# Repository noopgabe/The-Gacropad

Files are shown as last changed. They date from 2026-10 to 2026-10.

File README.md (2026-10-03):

# The GacroPad

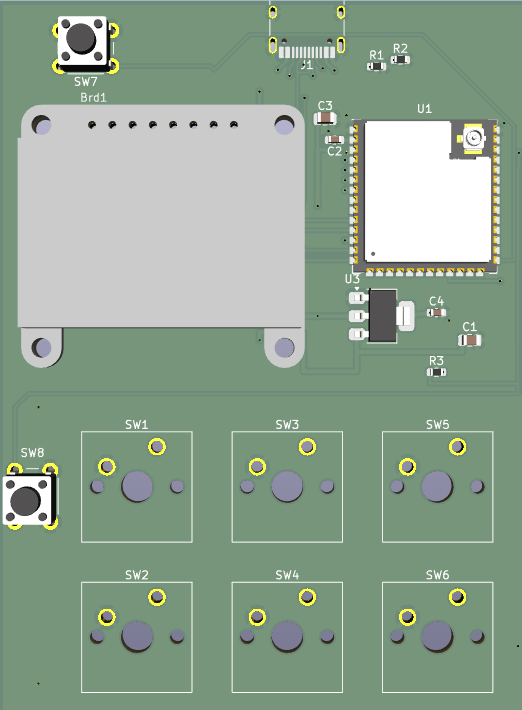
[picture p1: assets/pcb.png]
> 

A six-key macro pad that plugs into a PC as a USB keyboard, with a small OLED for whatever you feel like showing it. Time, stats, whatever. If it doesn't have it, make it.

I made this because I play Roblox. Roblox is very weird. Some games are intense, and some are calmer. If you couldn't tell, I play intensely. I also listen to music. Can you REALLY switch between music and being in the middle of a chase sequence? No. No you can't. This is why I built the GacroPad. I also need macros for some things, limited to, but not excluding:

- Complicated actions 
- Die of Death
- Soundboard

The screen helps in a way because I can see the time when I'm in a heavy chase and I can't hit F11 without getting myself hit in a chase.

---

The repo has two halves: the firmware that runs on the pad, and a GTK4 companion app. The pad is good itself. The companion app is the real business, but the firmware is where all the magic happens. The companion app is cooler, I swear on my life.

## The hardware

It's built around an **ESP32-S3-WROOM-1U**:

- a 1.3" SSD1306 128x64 I2C OLED (the address is probed at boot, so `0x3C` and `0x3D` both work)
- native USB, but \* 2: TinyUSB HID for the keyboard and media keys, and a CDC port for talking to the companion app.

Macros can send ordinary keystrokes, raw HID usages, media keys, text, and delays. They're stored in NVS, so they survive power cycles and reflashes. If that is one of your worries, let them be free!

## Building the firmware

```bash
pio run
```

That gives you `firmware.bin`, which is only the application. A _first_ flash over the ROM bootloader kinda needs the whole thing, so instead run this:

```bash
pio run -t mergedbin
```

That writes `.pio/build/gacropad/gacropad.bin`, which includes the bootloader, partition table, and app, ready to flash at offset `0x0`.

### Flashing

There's buttons. On the PCB. One is BOOT. One is RESET. Hold BOOT, and then hit RESET. After, you can flash it through various ways, but my favorite is esptool. For the sake of time, I will only place that.

```bash
esptool.py --port /dev/ttyUSB0 write_flash 0x0 .pio/build/gacropad/gacropad.bin
```

## The companion app

GTK4, via PyGObject, which means it wants the system Python:

```bash
sudo apt install python3-gi gir1.2-gtk-4.0
pip install -r companion/requirements.txt
cd companion && /usr/bin/python3 main.py
```

A plain venv usually won't have `gi`, which is why we have the `/usr/bin/python3`. The app finds the pad on its own if there's only one, and you should only have one anyway, since 2 is nuts and 3 is a mental health issue.

What it's for:

- Macro editing. Seriously, what else? Click a key to open its editor. Recording captures whatever you do but only while the editor window has focus, because why else? Just write it down on a notepad if you need to remember. This is why it works on Wayland without root. Esc stops. There's a "test fire" button, and presets if you're a baby and you don't like to record.
- OLED modes. `labels` (key names), `clock`, `stats` (CPU and memory), and `live` (two lines of text you control). The live lines are plain text pushed over serial, so anything can be there.

The key buttons push one slot at a time, meanwhile "push all" pushes all six. Of course.

## The serial protocol

Newline-delimited JSON, one request per line, one reply per line. If you're handy, this is maybe useful. _Maybe._ This usually isn't, but if you eventually figure it out, congratulations, you're a nerd.

```
{"cmd":"ping"}
{"cmd":"get","key":0}
{"cmd":"set","key":0,"slot":{"label":"K1","steps":[{"t":"raw","v":104,"hold":40}]}}
{"cmd":"press","key":0}
{"cmd":"oled","mode":"clock"}
{"cmd":"live","clock":"14:32","l1":"hello","l2":"world"}
{"cmd":"stats","cpu":12,"mem":40}
{"cmd":"reset"}
```

Replies always carry `ok`, and an `err` when it's false. The pad also emits unsolicited `{"ev":...}` lines of its own when you press a key.

Macro steps are `delay`, `text`, `media`, `raw`, `key`, `down`, and `up`, where `down` and `up` are for chords, like holding Ctrl and then tapping C.

## CAD files

Well, here's the thing. The case is not done yet. It will be done soon. Trust me, it won't be late. 

## Credits and confessions

Built with [U8g2](https://github.com/olikraus/u8g2) (thank you) and [ArduinoJson](https://github.com/bblanchon/ArduinoJson) (thank you too), and a great deal of beating the hugs out of the ESP32 Arduino HID API until it worked well.

The code comments are better than the actual code, unfortunately. I am not good at programming, or designing, or whatever. If you object, do not.

I have committed many sins (sloth, sloth, sloth, and sloth), and this is unfortunately my penance. This was lazy, but that's fine.

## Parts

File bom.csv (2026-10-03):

Item Name | Qty | Price (total) (USD) | Item link | Notes
ESP32-S3-WROOM-1U-N8 | 1 | 4.54 | https://www.lcsc.com/product-detail/C2980297.html
USB-C receptacle | 5 | 0.86 | https://www.lcsc.com/product-detail/C165948.html
10kΩ resistor | 100 | 0.39 | https://www.lcsc.com/product-detail/C965184.html
AMS1117-3.3 | 5 | 1.05 | https://www.lcsc.com/product-detail/C6186.html
Tactile button | 5 | 0.76 | https://www.lcsc.com/product-detail/C722171.html
10uF capacitor | 20 | 1.31 | https://www.lcsc.com/product-detail/C15850.html
100nF capacitor | 50 | 0.62 | https://www.lcsc.com/product-detail/C14663.html
1uF capacitor | 20 | 0.5 | https://www.lcsc.com/product-detail/C106858.html
5.1kΩ resistor | 100 | 0.15 | https://www.lcsc.com/product-detail/C23186.html
LCSC shipping + handling | N/A | 11.32 | N/A | standard shipping
JLC manufacturing + shipping | 5 | $7.38 | N/A | ditto
Adafruit oled | 1 | 19.95 | https://www.digikey.com/en/products/detail/adafruit-industries-llc/938/5774238
DigiKey shipping | N/A | 4.99 | N/A | standard usps ground advantage
Soldering iron | 1 | $10.64 | https://a.co/d/09gOBPuw | i have prime so its okie-dokie
Total Price (USD): | 64.46

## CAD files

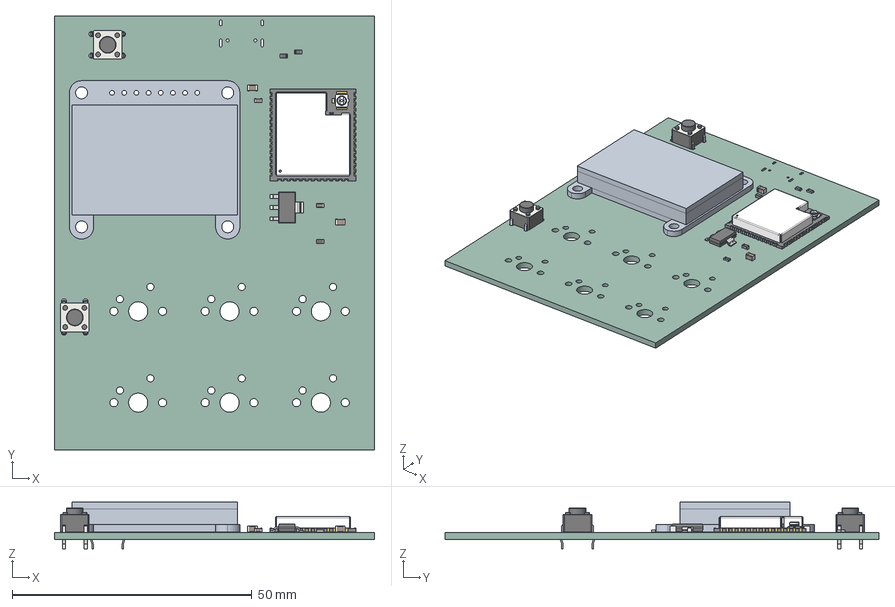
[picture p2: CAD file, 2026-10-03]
cad/gacropad.step
66.7 x 90.5 x 9.70 mm
C_0805_2012Metric x 2
R0201_20210301.STEP^R0201_20210301.STEP_Submodel-R0201_part_ DesignRootModel_ESP32-S3-WROOM-1U(2)_ESP32-S3-WROOM-1U_2 x 8
L0201_20210301.STEP^L0201_20210301.STEP_Submodel-L0201_part_ DesignRootModel_ESP32-S3-WROOM-1U(2)_ESP32-S3-WROOM-1U_2 x 2
C0201_20210301.STEP^C0201_20210301.STEP_Submodel-C0201_part_ DesignRootModel_ESP32-S3-WROOM-1U(2)_ESP32-S3-WROOM-1U_2 x 13
C0402_20210301.STEP^C0402_20210301.STEP_Submodel-C0402_part_ DesignRootModel_ESP32-S3-WROOM-1U(2)_ESP32-S3-WROOM-1U_2
I-IPEX.STEP^I-IPEX.STEP_Submodel-IPEX_3P_part_DesignRootModel_ ESP32-S3-WROOM-1U(2)_ESP32-S3-WROOM-1U_2
DFN1006.STEP^DFN1006.STEP_Submodel-SOD882_part_DesignRootModel_ ESP32-S3-WROOM-1U(2)_ESP32-S3-WROOM-1U_2
SOP8_rev1_20210308.STEP^SOP8_rev1_20210308.STEP_Submodel-SOP8_1P27_6P6_ part_DesignRootModel_ESP32-S3-WROOM-1U(2)_ESP32-S3-WROOM-1U_2
ESP32-S3_20210301.STEP^ESP32-S3_20210301.STEP_Submodel-QFN56_0P4_7_ part_DesignRootModel_ESP32-S3-WROOM-1U(2)_ESP32-S3-WROOM-1U_2
XTAL3225_20210301.STEP^XTAL3225_20210301.STEP_Submodel-XTAL3225_part_ DesignRootModel_ESP32-S3-WROOM-1U(2)_ESP32-S3-WROOM-1U_2
uid__4-111^DesignRootModel_ESP32-S3-WROOM-1U(2)_ESP32-S3-WROOM-1U_2
uid__4-112^DesignRootModel_ESP32-S3-WROOM-1U(2)_ESP32-S3-WROOM-1U_2
uid__4-113^DesignRootModel_ESP32-S3-WROOM-1U(2)_ESP32-S3-WROOM-1U_2
uid__4-130^DesignRootModel_ESP32-S3-WROOM-1U(2)_ESP32-S3-WROOM-1U_2
uid__4-131^DesignRootModel_ESP32-S3-WROOM-1U(2)_ESP32-S3-WROOM-1U_2
uid__4-132^DesignRootModel_ESP32-S3-WROOM-1U(2)_ESP32-S3-WROOM-1U_2
uid__4-148^DesignRootModel_ESP32-S3-WROOM-1U(2)_ESP32-S3-WROOM-1U_2
uid__4-149^DesignRootModel_ESP32-S3-WROOM-1U(2)_ESP32-S3-WROOM-1U_2
uid__4-150^DesignRootModel_ESP32-S3-WROOM-1U(2)_ESP32-S3-WROOM-1U_2
uid__1-253^DesignRootModel_ESP32-S3-WROOM-1U(2)_ESP32-S3-WROOM-1U_2
uid__1-254^DesignRootModel_ESP32-S3-WROOM-1U(2)_ESP32-S3-WROOM-1U_2
uid__1-256^DesignRootModel_ESP32-S3-WROOM-1U(2)_ESP32-S3-WROOM-1U_2
uid__1-257^DesignRootModel_ESP32-S3-WROOM-1U(2)_ESP32-S3-WROOM-1U_2
uid__1-266^DesignRootModel_ESP32-S3-WROOM-1U(2)_ESP32-S3-WROOM-1U_2
uid__1-269^DesignRootModel_ESP32-S3-WROOM-1U(2)_ESP32-S3-WROOM-1U_2
uid__1-270^DesignRootModel_ESP32-S3-WROOM-1U(2)_ESP32-S3-WROOM-1U_2
uid__1-271^DesignRootModel_ESP32-S3-WROOM-1U(2)_ESP32-S3-WROOM-1U_2
uid__1-272^DesignRootModel_ESP32-S3-WROOM-1U(2)_ESP32-S3-WROOM-1U_2
uid__1-273^DesignRootModel_ESP32-S3-WROOM-1U(2)_ESP32-S3-WROOM-1U_2
uid__1-274^DesignRootModel_ESP32-S3-WROOM-1U(2)_ESP32-S3-WROOM-1U_2
uid__1-275^DesignRootModel_ESP32-S3-WROOM-1U(2)_ESP32-S3-WROOM-1U_2
uid__1-276^DesignRootModel_ESP32-S3-WROOM-1U(2)_ESP32-S3-WROOM-1U_2
uid__1-277^DesignRootModel_ESP32-S3-WROOM-1U(2)_ESP32-S3-WROOM-1U_2
uid__1-280^DesignRootModel_ESP32-S3-WROOM-1U(2)_ESP32-S3-WROOM-1U_2
uid__1-292^DesignRootModel_ESP32-S3-WROOM-1U(2)_ESP32-S3-WROOM-1U_2
uid__1-293^DesignRootModel_ESP32-S3-WROOM-1U(2)_ESP32-S3-WROOM-1U_2
uid__1-297^DesignRootModel_ESP32-S3-WROOM-1U(2)_ESP32-S3-WROOM-1U_2
uid__1-300^DesignRootModel_ESP32-S3-WROOM-1U(2)_ESP32-S3-WROOM-1U_2
uid__1-301^DesignRootModel_ESP32-S3-WROOM-1U(2)_ESP32-S3-WROOM-1U_2
uid__1-302^DesignRootModel_ESP32-S3-WROOM-1U(2)_ESP32-S3-WROOM-1U_2
uid__1-303^DesignRootModel_ESP32-S3-WROOM-1U(2)_ESP32-S3-WROOM-1U_2
uid__1-307^DesignRootModel_ESP32-S3-WROOM-1U(2)_ESP32-S3-WROOM-1U_2
uid__1-313^DesignRootModel_ESP32-S3-WROOM-1U(2)_ESP32-S3-WROOM-1U_2
uid__1-319^DesignRootModel_ESP32-S3-WROOM-1U(2)_ESP32-S3-WROOM-1U_2
uid__1-320^DesignRootModel_ESP32-S3-WROOM-1U(2)_ESP32-S3-WROOM-1U_2
uid__1-321^DesignRootModel_ESP32-S3-WROOM-1U(2)_ESP32-S3-WROOM-1U_2
uid__1-328^DesignRootModel_ESP32-S3-WROOM-1U(2)_ESP32-S3-WROOM-1U_2
uid__1-332^DesignRootModel_ESP32-S3-WROOM-1U(2)_ESP32-S3-WROOM-1U_2
uid__1-333^DesignRootModel_ESP32-S3-WROOM-1U(2)_ESP32-S3-WROOM-1U_2
uid__1-334^DesignRootModel_ESP32-S3-WROOM-1U(2)_ESP32-S3-WROOM-1U_2
uid__1-335^DesignRootModel_ESP32-S3-WROOM-1U(2)_ESP32-S3-WROOM-1U_2
uid__1-336^DesignRootModel_ESP32-S3-WROOM-1U(2)_ESP32-S3-WROOM-1U_2
uid__1-337^DesignRootModel_ESP32-S3-WROOM-1U(2)_ESP32-S3-WROOM-1U_2
uid__1-338^DesignRootModel_ESP32-S3-WROOM-1U(2)_ESP32-S3-WROOM-1U_2
uid__1-339^DesignRootModel_ESP32-S3-WROOM-1U(2)_ESP32-S3-WROOM-1U_2
uid__1-340^DesignRootModel_ESP32-S3-WROOM-1U(2)_ESP32-S3-WROOM-1U_2
uid__1-341^DesignRootModel_ESP32-S3-WROOM-1U(2)_ESP32-S3-WROOM-1U_2
uid__1-342^DesignRootModel_ESP32-S3-WROOM-1U(2)_ESP32-S3-WROOM-1U_2
uid__1-343^DesignRootModel_ESP32-S3-WROOM-1U(2)_ESP32-S3-WROOM-1U_2
uid__1-344^DesignRootModel_ESP32-S3-WROOM-1U(2)_ESP32-S3-WROOM-1U_2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

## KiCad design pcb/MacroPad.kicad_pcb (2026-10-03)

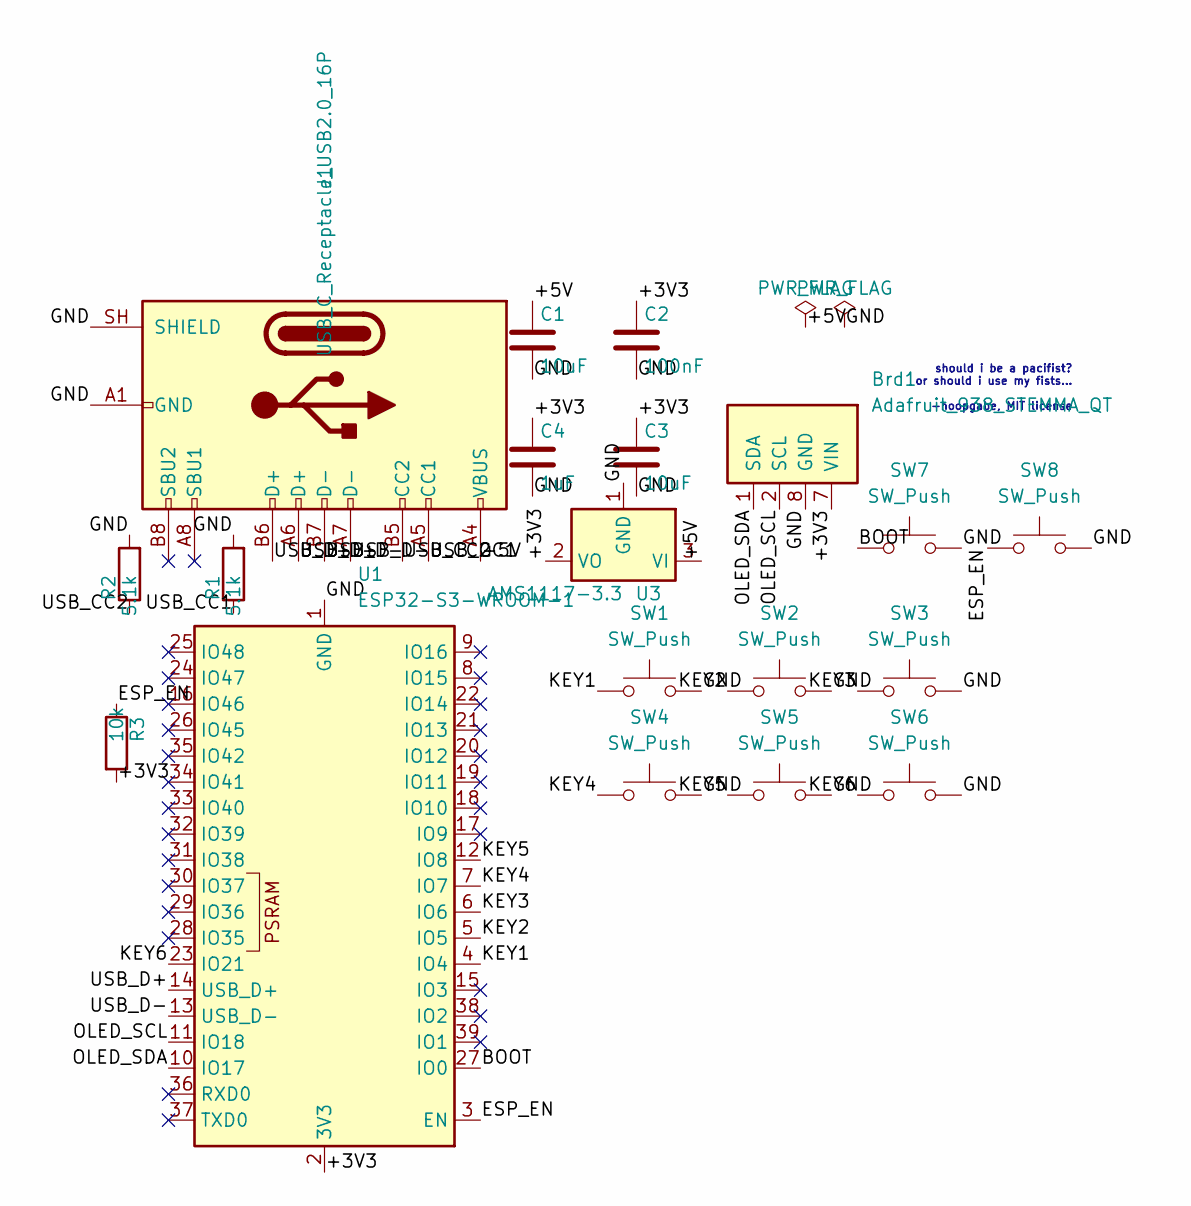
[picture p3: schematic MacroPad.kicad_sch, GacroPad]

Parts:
Brd1: Adafruit_938_STEMMA_QT
C1, C3: 10uF; C_0805_2012Metric
C2: 100nF; C_0603_1608Metric
C4: 1uF; C_0603_1608Metric
J1: USB_C_Receptacle_USB2.0_16P; USB_C_Receptacle_HRO_TYPE-C-31-M-12
R1, R2: 5.1k; R_0603_1608Metric
R3: 10k; R_0603_1608Metric
SW1, SW2, SW3, SW4, SW5, SW6: SW_Push; SW_Cherry_MX_1.00u_PCB
SW7, SW8: SW_Push; SW_PUSH_6mm_H5mm
U1: ESP32-S3-WROOM-1; ESP32-S3-WROOM-1U
U3: AMS1117-3.3; SOT-223-3_TabPin2; MPN AMS1117-3.3

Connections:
/+3V3: Brd1.7 (VIN), C2.1, C3.1, C4.1, R3.2, U1.2 (3V3), U3.2 (VO)
/+5V: C1.1, J1.A4 (VBUS), J1.A9 (VBUS), J1.B4 (VBUS), J1.B9 (VBUS), U3.3 (VI)
/BOOT: SW7.1, U1.27 (IO0)
/ESP_EN: R3.1, SW8.1, U1.3 (EN)
/GND: Brd1.8 (GND), C1.2, C2.2, C3.2, C4.2, J1.A1 (GND), J1.A12 (GND), J1.B1 (GND), J1.B12 (GND), J1.SH (SHIELD), R1.2, R2.2, SW1.2, SW2.2, SW3.2, SW4.2, SW5.2, SW6.2, SW7.2, SW8.2, U1.1 (GND), U1.40 (GND), U1.41 (GND), U3.1 (GND)
/KEY1: SW1.1, U1.4 (IO4)
/KEY2: SW2.1, U1.5 (IO5)
/KEY3: SW3.1, U1.6 (IO6)
/KEY4: SW4.1, U1.7 (IO7)
/KEY5: SW5.1, U1.12 (IO8)
/KEY6: SW6.1, U1.23 (IO21)
/OLED_SCL: Brd1.2 (SCL), U1.11 (IO18)
/OLED_SDA: Brd1.1 (SDA), U1.10 (IO17)
/USB_CC1: J1.A5 (CC1), R1.1
/USB_CC2: J1.B5 (CC2), R2.1
/USB_D+: J1.A6 (D+), J1.B6 (D+), U1.14 (USB_D+)
/USB_D-: J1.A7 (D-), J1.B7 (D-), U1.13 (USB_D-)

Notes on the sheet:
should i be a pacifist? or should i use my fists... -noopgabe, MIT license

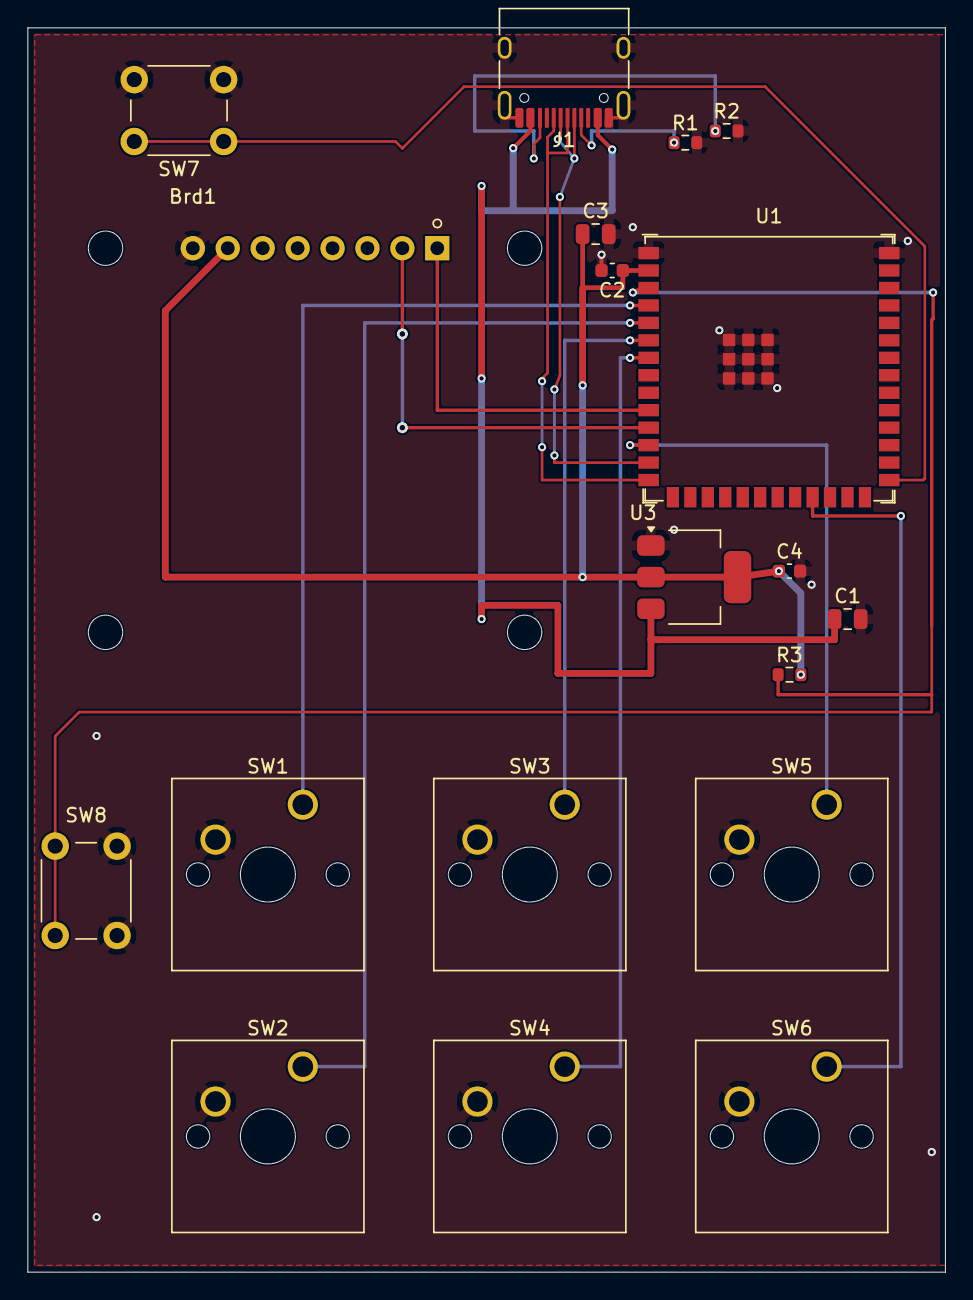
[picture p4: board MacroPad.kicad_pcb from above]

Board: 2 copper layers, 66.7 x 90.5 mm, 19 parts (0 on the bottom side), 17 nets.

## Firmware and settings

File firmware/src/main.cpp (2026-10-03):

// GacroPad firmware v1 with ESP32-S3-WROOM-1U, Arduino + Tiny USB. 
// I have nothing funny to say anymore

// Companion app talks newline-JSON over serial and mooches this thing on the cheek whenever it needs to change stuff.  
// The OLED is a 1.3" SH1106 128x64 I2C display.

#include <Arduino.h>
#include <Preferences.h>
#include <Wire.h>
#include <U8g2lib.h>
#include <ArduinoJson.h>
#include "USB.h"
#include "USBHIDKeyboard.h"
#include "USBHIDConsumerControl.h"

#define FW_VERSION "1.0.0"
#define NKEYS 6
#define PIN_OLED_SDA 46
#define PIN_OLED_SCL 45

static const uint8_t KEY_PINS[NKEYS] = {10, 9, 8, 7, 6, 40};
static const uint8_t DEFAULT_RAW[NKEYS] = {0x68, 0x69, 0x6A, 0x6B, 0x6C, 0x6D}; // F13-F18
static const char *SLOT_KEYS[NKEYS] = {"m0", "m1", "m2", "m3", "m4", "m5"};
#define MAX_STEPS 64
#define MAX_JSON 3072
#define DEBOUNCE_MS 25
#define LABEL_MAX 10

USBHIDKeyboard Keyboard;
USBHIDConsumerControl Consumer;
Preferences prefs;
U8G2_SH1106_128X64_NONAME_F_HW_I2C u8g2(U8G2_R0, U8X8_PIN_NONE, PIN_OLED_SCL, PIN_OLED_SDA);

struct Live {
    String clock = "--:--"; 
    String date = "";
    String l1 = "GacroPad";
    String l2 = "";
    int cpu = -1, mem = -1;
} live;
String oledMode = "labels";
int lastKey = -1;
uint32_t lastKeyAt = 0;
bool playing = false;

static bool keyValid(int k) { return k >= 0 && k < NKEYS; }

static String defaultSlot(int k) {
    char b[128];
    snprintf(b, sizeof b,
             "{\"label\":\"K%d\",\"steps\":[{\"t\":\"raw\",\"v\":%d,\"hold\":40}]}",
             k + 1, DEFAULT_RAW[k]);
    return String(b);
}

// flowers bloom in your heart
static String slotLabel(const char *json) {
    JsonDocument d;
    if (deserializeJson(d, json)) return "?";
    const char *l = d["label"] | "?";
    return String(l).substring(0, LABEL_MAX);
}

// Labels are cached: reading them from NVS every OLED frame is 6 flash lookups per 200ms.
static String slotLabels[NKEYS];

// getString's String overload has no length cap; the char* one silently drops slots too big to read.
static String loadSlot(int k) {
    String s = prefs.getString(SLOT_KEYS[k], "");
    if (!s.length()) { s = defaultSlot(k); prefs.putString(SLOT_KEYS[k], s); }
    return s;
}

// The one place a slot changes: NVS and the label cache move together, or they drift.
static void setSlot(int k, const char *json) {
    prefs.putString(SLOT_KEYS[k], json);
    slotLabels[k] = slotLabel(json);
}

static void loadLabels() {
    for (int k = 0; k < NKEYS; k++) {
        String s = loadSlot(k);
        slotLabels[k] = slotLabel(s.c_str());
    }
}

// Macro playback. The core functionality, how nice. 
static void playSteps(JsonArray steps) {
    int n = 0; 
    for (JsonObject st : steps) {
        if (++n > MAX_STEPS) break;
        const char *t = st["t"] | "";
        if (!strcmp(t, "delay")) {
            delay(st["ms"] | 50);
        } else if (!strcmp(t, "text")) {
            const char *s = st["s"] | "";
            Keyboard.print(s);
            delay(15);
        } else if (!strcmp(t, "media")) {
            uint16_t v = st["v"] | 0;
            if (v) { Consumer.press(v); delay(st["hold"] | 120); Consumer.release(); }
            delay(15);
        } else if (!strcmp(t, "raw")) {
            uint8_t v = st["v"] | 0;
            if (v) { Keyboard.pressRaw(v); delay(st["hold"] | 40); Keyboard.releaseRaw(v); }
            delay(15);
        } else if (!strcmp(t, "key")) {
            uint8_t v = st["v"] | 0;
            if (v) { Keyboard.press(v); delay(st["hold"] | 40); Keyboard.release(v); }
            delay(15);
        } else if (!strcmp(t, "down")) {
            uint8_t v = st["v"] | 0;
            if (v) Keyboard.press(v); 
        } else if (!strcmp(t, "up")) {
            uint8_t v = st["v"] | 0;
            if (v) Keyboard.release(v); // release(), not releaseRaw(): an "up" step pairs with a press()
            delay(10);
      }
    }
    Keyboard.releaseAll();
    Consumer.release();
}

static void playKey(int k) {
    if (!keyValid(k) || playing) return;
    playing = true;
    lastKey = k;
    lastKeyAt = millis();
    Serial.printf("{\"ev\":\"play\",\"key\":%d}\n", k);
    String slot = loadSlot(k);
    JsonDocument d;
    if (!deserializeJson(d, slot) && d["steps"].is<JsonArray>())
        playSteps(d["steps"].as<JsonArray>());
    playing = false;
}

// Serial stuff
static char lineBuf[MAX_JSON + 64];
static size_t lineLen = 0;

static void reply(JsonDocument &d) {
    serializeJson(d, Serial);
    Serial.println();
}

static void handleLine(const char *line) {
    JsonDocument d;
    JsonDocument out;
    if (deserializeJson(d, line)) { out["ok"] = false; out["err"] = "json"; reply(out); return; }
    const char *cmd = d["cmd"] | "";
    if (!strcmp(cmd, "ping")) {
        out ["ok"] = true; out ["proto"] = 1; out["fw"] = FW_VERSION; out["keys"] = NKEYS;
    } else if (!strcmp(cmd, "get")) {
        int k = d["key"] | -1;
        if (!keyValid(k)) { out["ok"] = false; out["err"] = "key"; }
        else {
            JsonDocument s;
            deserializeJson(s, loadSlot(k));
            out["ok"] = true; out["slot"] = s.as<JsonObjectConst>();
        }
    } else if (!strcmp(cmd, "set")) {
        int k = d["key"] | -1;
        if (!keyValid(k) || !d["slot"].is<JsonObject>()) { out["ok"] = false; out["err"] = "arg"; }
        else {
            String s;
            serializeJson(d["slot"], s);
            if (s.length() > MAX_JSON) { out["ok"] = false; out["err"] = "too big"; }
            else { setSlot(k, s.c_str()); out["ok"] = true; }
        }
    } else if (!strcmp(cmd, "press")) {
        int k = d["key"] | -1;
        if (!keyValid(k)) { out["ok"] = false; out["err"] = "key"; }
        else { out["ok"] = true; reply(out); playKey(k); return; }
    } else if (!strcmp(cmd, "oled")) {
        const char *m = d["mode"] | "";
        if (strcmp(m, "labels") && strcmp(m, "clock") && strcmp(m, "stats") && strcmp(m, "live")) {
            out["ok"] = false; out["err"] = "mode";
        } else { oledMode = m; prefs.putString("oledmode", m); out["ok"] = true; }
    } else if (!strcmp(cmd, "live")) {
        // Clipped to what the 6x10 font fits, here once, instead of per frame in every draw function.
        if (d["clock"].is<const char *>()) live.clock = String((const char *)d["clock"]).substring(0, 21);
        if (d["date"].is<const char *>()) live.date = String((const char *)d["date"]).substring(0, 20);
        if (d["l1"].is<const char *>()) live.l1 = String((const char *)d["l1"]).substring(0, 21);
        if (d["l2"].is<const char *>()) live.l2 = String((const char *)d["l2"]).substring(0, 21);
        out["ok"] = true;
    } else if (!strcmp(cmd, "stats")) {
        // Only the stats screen reads cpu/mem; writing them into live.l2 would clobber live mode's line 2.
        if (d["cpu"].is<int>()) live.cpu = d["cpu"];
        if (d["mem"].is<int>()) live.mem = d["mem"];
        out["ok"] = true;
    } else if (!strcmp(cmd, "reset")) {
        for (int k = 0; k < NKEYS; k++) { String s = defaultSlot(k); setSlot(k, s.c_str()); }
        oledMode = "labels";
        prefs.putString("oledmode", oledMode);
        out["ok"] = true;
    } else {
        out["ok"] = false; out["err"] = "cmd";
    }
    reply(out);
}

static void pollSerial() {
    while (Serial.available()) {
        char c = (char)Serial.read();
        if (c == '\n') {
            lineBuf[lineLen] = 0;
            if (lineLen) handleLine(lineBuf);
            lineLen = 0;
        } else if (c != '\r' && lineLen < sizeof(lineBuf) - 1) {
            lineBuf[lineLen++] = c;
        }
    }
}

// The buttons! 
static uint8_t stableState[NKEYS] = {HIGH, HIGH, HIGH, HIGH, HIGH, HIGH}; 
static uint8_t candState[NKEYS] = {HIGH, HIGH, HIGH, HIGH, HIGH, HIGH};
static uint32_t candSince[NKEYS] = {0};

static void pollKeys() {
    uint32_t now = millis();
    for (int k = 0; k < NKEYS; k++) {
        uint8_t r = digitalRead(KEY_PINS[k]);
        if (r == stableState[k]) { candState[k] = r; continue; }                        // bounced back, drop the candidate
        if (r != candState[k]) { candState[k] = r; candSince[k] = now; continue; }      // new candidate, restart the timer
        if (now - candSince[k] < DEBOUNCE_MS) continue;                                // candidate hasn't settled yet
        stableState[k] = r;
        if (r == LOW) {
            Serial.printf("{\"ev\":\"press\",\"key\":%d}\n", k);
            playKey(k);
        }
    }
}

// The OLED! 
static void drawLabels() {
    u8g2.setFont(u8g2_font_6x10_tf);
    u8g2.drawStr(0, 9, "GacroPad");
    u8g2.drawStr(128 - 6 * (int)live.clock.length(), 9, live.clock.c_str());
    for (int k = 0; k < NKEYS; k++) {
        int col = k % 2, row = k /2;
        int x = col * 64, y = 12 + row * 14;
        char l[LABEL_MAX + 4]; // key digits, ':', label, terminator
        snprintf(l, sizeof l, "%d:%s", k + 1, slotLabels[k].c_str());
        if (k == lastKey && millis() - lastKeyAt < 800) {
            u8g2.drawBox(x, y - 10, 63, 12);
            u8g2.setDrawColor(0);
            u8g2.drawStr(x + 2, y - 1, l);
            u8g2.setDrawColor(1);
        } else {
            u8g2.drawStr(x + 2, y - 1, l);
        }
    }
    u8g2.drawStr(0, 63, live.l2.c_str());
}

static void drawClock() {
    u8g2.setFont(u8g2_font_logisoso16_tr);
    u8g2.drawStr(22, 32, live.clock.c_str());
    u8g2.setFont(u8g2_font_6x10_tf);
    u8g2.drawStr(24, 46, live.date.c_str());
    u8g2.drawStr(0, 63, live.l1.c_str());
}

static void drawStats() {
    char b[32];
    u8g2.setFont(u8g2_font_6x10_tr);
    u8g2.drawStr(0, 12, "GacroPad stats");
    if (live.cpu < 0) strcpy(b, "CPU: idk (no sync)");
    else snprintf(b, sizeof b, "CPU: %d%% MEM: %d%%", live.cpu, live.mem);
    u8g2.drawStr(0, 28, b);
    snprintf(b, sizeof b, "up %lus", (unsigned long)(millis() / 1000));
    u8g2.drawStr(0, 42, b);
    u8g2.drawStr(0, 63, live.clock.c_str());
}

static void drawLive() {
    u8g2.setFont(u8g2_font_6x10_tr);
    u8g2.drawStr(0, 24, live.l1.c_str());
    u8g2.drawStr(0, 44, live.l2.c_str());
    u8g2.drawStr(0, 63, live.clock.c_str());
}

static void drawOled() {
    u8g2.clearBuffer();
    if (oledMode == "clock") drawClock();
    else if (oledMode == "stats") drawStats();
    else if (oledMode == "live") drawLive();
    else drawLabels();
    u8g2.sendBuffer();
}

// Setup AND loop.

static uint8_t i2cProbe() {
    Wire.begin(PIN_OLED_SDA, PIN_OLED_SCL);
    for (uint8_t a : {0x3Cu, 0x3Du}) {
        Wire.beginTransmission(a);
        if (!Wire.endTransmission()) return a;
    }
    return 0x3C;
}

void setup() {
    for (int k = 0; k < NKEYS; k++) pinMode(KEY_PINS[k], INPUT_PULLUP);
    Serial.begin(115200); // man i don't need this much serial in my bowl, too many calories
    prefs.begin("gacro", false); // that wasnt a funny joke i apologize sincerely
    oledMode = prefs.getString("oledmode", "labels");
    loadLabels();
    const uint8_t oledAddr = i2cProbe();
    u8g2.setI2CAddress(oledAddr * 2);
    u8g2.begin();
    USB.productName("The GacroPad");
    USB.manufacturerName("noopgabe");
    USB.serialNumber("42069"); // customize this to be whatever you want. default is 42069 because i am a funny
    Keyboard.begin();
    Consumer.begin();
    USB.begin();
    drawOled();
    Serial.println("{\"ev\":\"boot\",\"fw\":\"" FW_VERSION "\"}");
}

void loop() {
    pollSerial();
    pollKeys();
    static uint32_t lastDraw = 0;
    const uint32_t now = millis();
    if (now - lastDraw > 200) { lastDraw = now; drawOled(); }
    delay(2);
}

// I have served my penance. I am free. 

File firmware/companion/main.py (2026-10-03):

#!/usr/bin/env python3
"""This is the companion app for the GacroPad. How does it work, you may ask? It's just GTK4. With Python. Sad, I know.
Run /usr/bin/python3 main.py (you will need python3-gi, gir1.2-gtk-4.0, pyserial, psutil, and to flash you will need esptool) to launch the tool.

Recording is done when the window is focused, and it will not listen if it is not focused. This is how it works well on Wayland, and it
doesn't need root. Global capture soon(tm), but it already works anyway so who gives a freak. You're not gonna get it probably.

It does what you need to. Change the oled, change the macros, push them to the pad. Gets scary complicated, fast.

Works on Linux. WinUI port eventually. MacOS port maybe. I don't think it's gonna work out for MacOS in the first place anyway."""
import copy
import datetime
import json
import sys
import threading
import time

import gi
gi.require_version("Gtk", "4.0")
gi.require_version("Gdk", "4.0")
from gi.repository import Gdk, Glib, Gtk

import gacro

NO_PORT = "none found oopsies"

MODS = {"Control_L": 0x80, "Shift_L": 0x81, "Alt_L": 0x82, "Super_L": 0x83,
        "Control_R": 0x84, "Shift_R": 0x85, "Alt_R": 0x86, "Super_R": 0x87}
SPECIAL = {"Return": 0xB0, "Escape": 0xB1, "BackSpace": 0xB2, "Tab": 0xB3,
           "Insert": 0xD1, "Home": 0xD2, "Page_Up": 0xD3, "Delete": 0xD4,
           "End": 0xD5, "Page_Down": 0xD6, "Right": 0xD7, "Left": 0xD8,
           "Down": 0xD9, "Up": 0xDA, "Caps_Lock": 0xC1,
           **{f"F{i}": 0xC1 + i for i in range (1, 13)}}
MEDIA = {"AudioMute": 0xE2, "AudioVolDown": 0xE9, "AudioVolUp": 0xEA,
         "AudioPlay": 0xCD, "AudioNext": 0xB5, "AudioPrev": 0xB6, "AudioStop": 0xB7,}
PRESETS = {
    "Copy": [("down", 0x80), ("down", 99), ("up", 99), ("up", 0x80)],
    "Paste": [("down", 0x80), ("down", 118), ("up", 118), ("up", 0x80)],
    "Cut": [("down", 0x80), ("down", 120), ("up", 120), ("up", 0x80)],
    "Undo": [("down", 0x80), ("down", 122), ("up", 122), ("up", 0x80)],
    "Mute": [("media", 0xE2,)], "Play/Pause": [("media", 0xCD,)],
    "Vol+": [("media", 0xE9,)], "Vol-": [("media", 0xEA,)],
    "Next": [("media", 0xB5,)], "Prev": [("media", 0xB6,)],
}

# WARNING! If yee go beyond this point, you will suffer human-unreadable code. You have been warned.
# I make code very obfuscated not on purpose, though most people will think I am just a sadist.
def keyval_step(keyval):
    name = Gdk.keyval_name(keyval) or ""
    if name in MEDIA:
        return ("media", MEDIA[name])
    if name in MODS:
        return ("key", MODS[name])
    if name in SPECIAL:
        return ("key", SPECIAL[name])
    u = Gdk.keyval_to_unicode(keyval)
    if 32 <= u < 127:
        return ("key", u)
    return (None, name)

def dd_text(dd):
    obj = dd.get_selected_item()
    return obj.get_string() if obj else ""

def summarize(slot):
    parts = []
    for st in slot.get("steps", [])[:8]:
        t = st.get("t")
        if t in ("key", "down"):
            v = st["v"]
            parts.append({0x80: "C", 0x81: "S", 0x82: "A", 0x83: "G"}.get(v, chr(v) if 32 <= v < 127 else f"{v:02X}"))
        elif t == "media":
            parts.append("M")
        elif t == "text":
            parts.append("T")
    s = "+".join(p for p in parts if p) if parts else "empty"
    return s[:24]

def cpu_mem():
    try:
        import psutil
        return int(psutil.cpu_percent(interval=None)), int(psutil.virtual_memory().percent)
    except ImportError:
        return -1, -1

class App(Gtk.Application):
    def __init__(self):
        super().__init__(application_id="xyz.noopgabe.GacroPad")
        self.pad = None
        self.lock = threading.Lock()
        self.slots = [{"label": f"K{i+1}", "steps": []} for i in range (6)]
        self.live_on = False
        self.live_thread = None
        self.live_l1 = ""
        self.live_l2 = ""

    def do_activate(self):
        w = Gtk.ApplicationWindow(application=self, title="GacroPad", default_width=520, default_height=560)
        box = Gtk.Box(orientation=Gtk.Orientation.VERTICAL, spacing=8)
        box.set_margin_top(10); box.set_margin_bottom(10)
        box.set_margin_start(12); box.set_margin_end(12)
        w.set_child(box)

        hint = Gtk.Box(spacing=6)
        hint.append(Gtk.Label(label="tip: reserve K4 and K6 to go back/forward to the next macro menu, or keep all six free for one page.",
                              hexpand=True, xalign=0))
        hclose = Gtk.Button(label="X")
        hclose.connect("clicked", lambda *a: box.remove(hint))
        hint.append(hclose)
        box.append(hint)

        prow = Gtk.Box(spacing=6)
        self.port_store = Gtk.StringList.new([])
        self.port_combo = Gtk.DropDown(model=self.port_store)
        self.refresh_ports()
        prow.append(Gtk.Label(label="port"))
        prow.append(self.port_combo)
        rb = Gtk.Button(label="rescan")
        rb.connect("clicked", lambda *a: self.refresh_ports())
        prow.append(rb)
        self.conn_btn = Gtk.Button(label="connect")
        self.conn_btn.connect("clicked", self.on_connect)
        prow.append(self.conn_btn)
        self.status = Gtk.Label(label="not connected", xalign=0)
        prow.append(self.status)
        box.append(prow)

        grid = Gtk.Grid(column_spacing=8, row_spacing=8, column_homogeneous=True)
        self.key_btns = []
        for k in range(6):
            b = Gtk.Button()
            b.connect("clicked", self.on_edit, k)
            grid.attach(b, k % 2, k // 2, 1, 1)
            self.key_btns.append(b)
        box.append(grid)
        self.refresh_keys()

        push = Gtk.Button(label="push all to pad (no reflash!)")
        push.connect("clicked", self.on_push_all)
        box.append(push)

        orow = Gtk.Box(spacing=6)
        orow.append(Gtk.Label(label="oled:"))
        self.oled_modes = ("labels", "clock", "stats", "live")
        self.oled_combo = Gtk.DropDown.new_from_strings(self.oled_modes)
        orow.append(self.oled_combo)
        self.l1 = Gtk.Entry(placeholder_text="live line 1")
        self.l2 = Gtk.Entry(placeholder_text="live line 2")
        self.l1.connect("changed", self.cache_live_text)
        self.l2.connect("changed", self.cache_live_text)
        orow.append(self.l1); orow.append(self.l2)
        ob = Gtk.Button(label="apply")
        ob.connect("clicked", self.on_oled)
        orow.append(ob)
        box.append(orow)

        lrow = Gtk.Box(spacing=6)
        self.live_btn = Gtk.ToggleButton(label="background live: off")
        self.live_btn.connect("toggled", self.on_live)
        lrow.append(self.live_btn)
        lrow.append(Gtk.Label(label="streams clock + cpu/mem every 2s"))
        box.append(lrow)
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

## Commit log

2026-09-27 add: Finish firmware, clean up some stuff, add gitignore, finish up a few things, and squash bugs (AI assisted task).
    The bug squashing was partially a test of capabilities for Space Bunny. With some thorough investigation, this is, without a doubt, Gemini 4 Pro. I will get in touch with the right people to make sure this is correct.
    [gacro.py, main.cpp, main.py]
2026-10-03 fix: reorganize, prepare for grant submission
    [MacroPad.kicad_pcb, MacroPad.kicad_sch, bom.csv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]
